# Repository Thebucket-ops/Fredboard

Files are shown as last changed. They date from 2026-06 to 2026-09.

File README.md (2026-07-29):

# ***THE FREDBOARD V1/V2***
fred is the seal

  The fredboard is a custom pi pico devboard:
  - the v2 has a MPU-6500 and has a reboot button with a led to indicate the restart;
  - the v1 (untested) allows to use all but one pins provided by the rp2040, and has a led to indicate when the devboard is powered

## **V2 (TO BE APPROVED)**

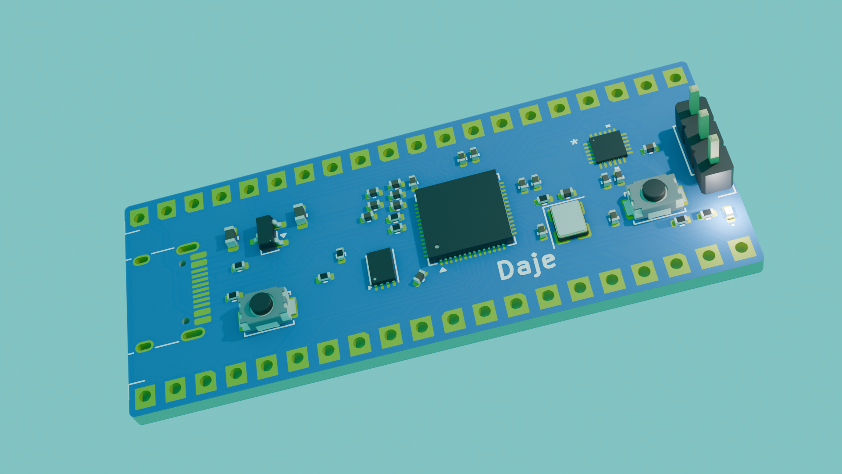
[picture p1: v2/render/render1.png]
front of the fredboard v2 boring side of the fredboard

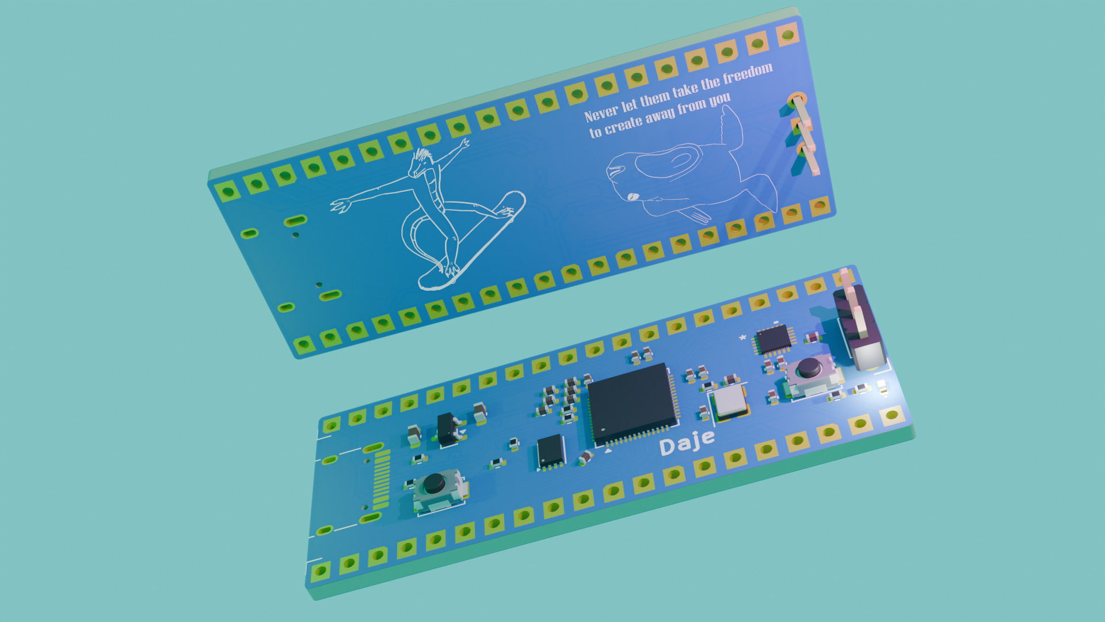
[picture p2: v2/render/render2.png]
back of the fredboard v2 look at that lizard smiling while riding his long skateboard

(Fred is the sea lion)

### **SCHEMATICS**
  Here's the schematic for the pcb, you can see the whole project from /v2/PCB

The Schematic for the v2 project schematic

### **THE PCB**
  This is the pcb, front and back (image art can be found on /img/devboard):

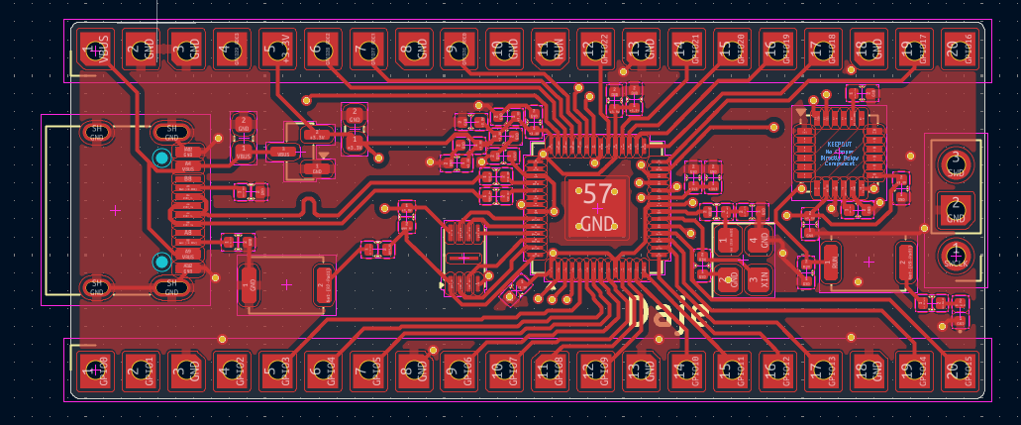
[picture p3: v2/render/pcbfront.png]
The pcb front v2 PCB front

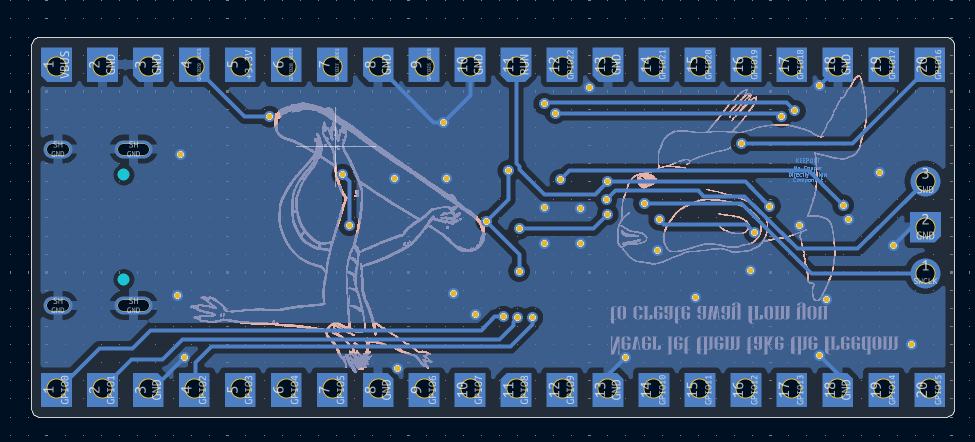
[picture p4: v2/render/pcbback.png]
The pcb back v2 PCB front


### **PINOUT**
  Here's a diagram for the pinout of the v2, for more information on each pins capabilities, look up the rp2040 datasheet

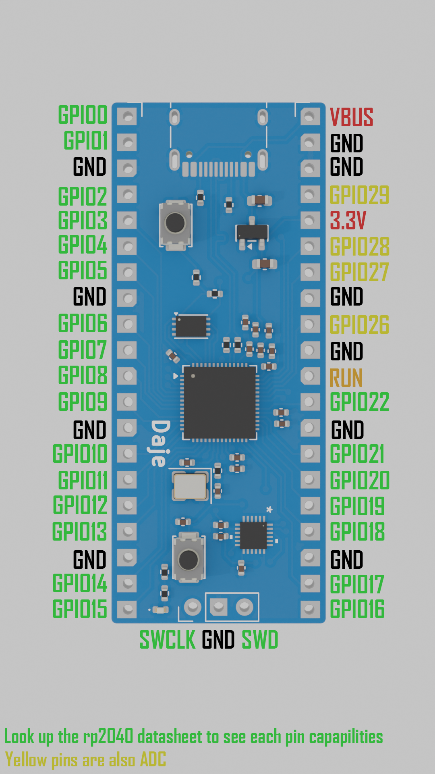
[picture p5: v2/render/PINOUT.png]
pinout


### **BOM and Gerber**
  The Bill Of Materials and the Gerber files can be found in the /v2/PCB/production folder, these are the required materials:

 - 2 33pF 0402 capacitors
 - 13 0.1uF 0402 capacitors
 - 2 1uF 0402 capacitors
 - 2 10uF 0603 capacitors
 - 1 10 nF 0402 capacitor
 - 1 0402 white led
 - 1 USB_C_Receptacle_USB2.0_14P
 - 2 pinheaders 1x20 (optional)
 - 1 pinheader 1x3 (optional)
 - 2 0402 27 ohm resistors
 - 1 0402 150 ohm resistor
 - 3 0402 1K resistors
 - 2 0402 5.1K resistors
 - 1 0402 10K resistor
 - 2 SW_Push_SPST_NO_Alps_SKRK button
 - 1 RP2040
 - 1 MCP1700x-330xxTT
 - 1 W25Q16JVUXIQ TR flash memory
 - 1 Crystal_SMD_3225-4Pin_3.2x2.5mm
 - 1 MPU-6500

## **V1 (UNTESTED)**
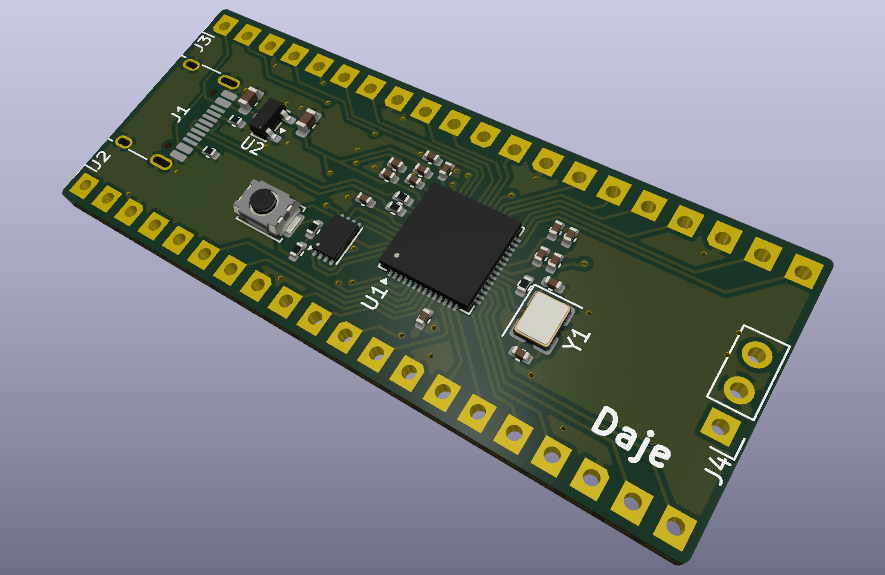
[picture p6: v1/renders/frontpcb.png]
front of the fredboard boring side of the fredboard

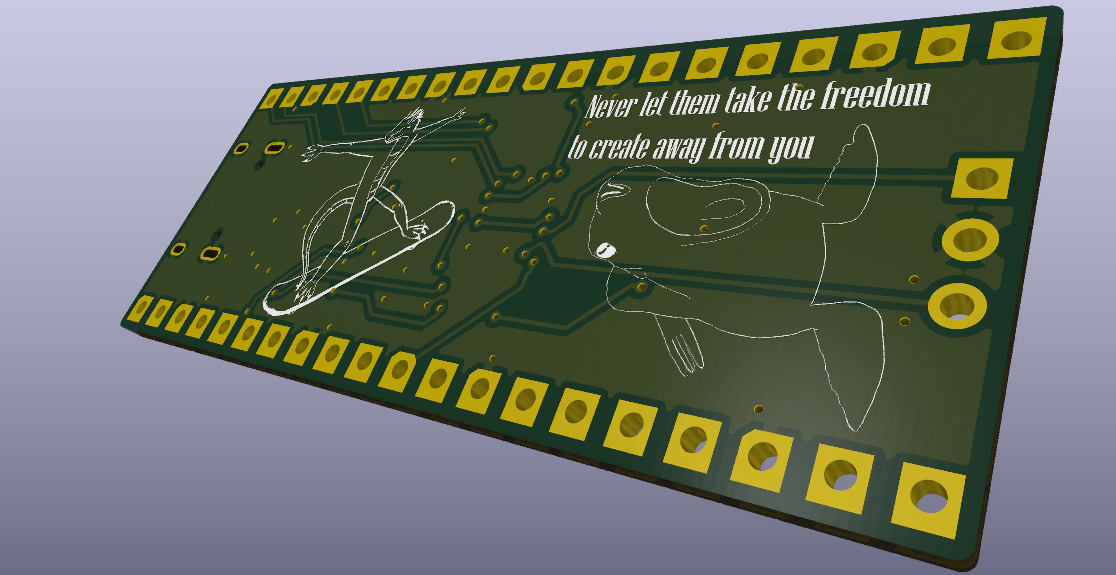
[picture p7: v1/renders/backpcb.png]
back of the fredboard look at that lizard smiling while riding his long skateboard


### **SCHEMATICS**
  Here's the schematic for the pcb, you can see the whole project from /PCB

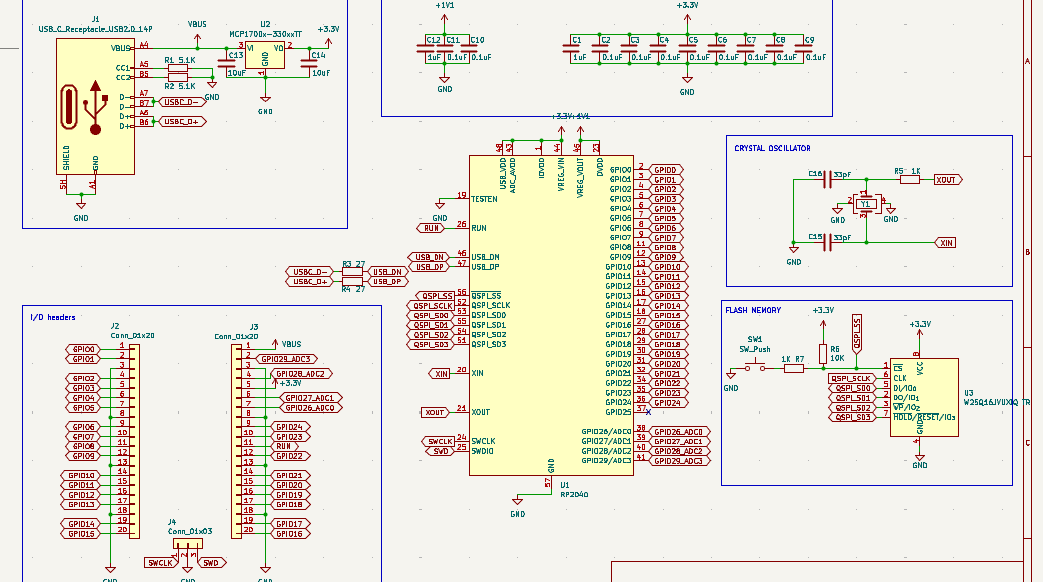
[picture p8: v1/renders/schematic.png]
The Schematic for the project schematic


### **THE PCB**
  This is the pcb, front and back (image art can be found on /img/devboard):

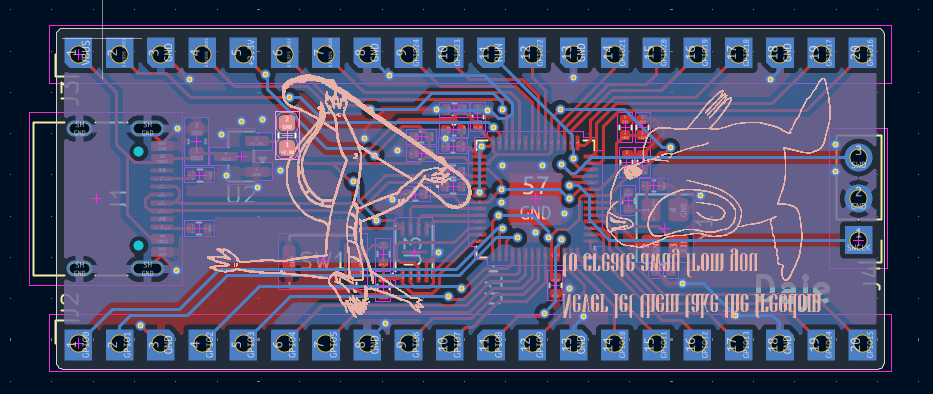
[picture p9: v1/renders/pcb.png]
The pcb PCB


### **BOM and Gerber**
  The Bill Of Materials and the Gerber files can be found in the /PCB/production folder, these are the required materials:

 - 10 0.1uF 0402 capacitors
 - 2 1uF 0402 capacitors
 - 2 10uF 0603 capacitors
 - 2 33pF 0402 capacitors
 - 1 0402 white led
 - 1 USB_C_Receptacle_USB2.0_14P
 - 2 pinheaders 1x20 (optional)
 - 1 pinheader 1x3 (optional)
 - 2 0402 5.1K resistors
 - 2 0402 27 ohm resistors
 - 2 0402 1K resistors
 - 1 0402 10K resistor
 - 1 SW_Push_SPST_NO_Alps_SKRK button
 - 1 RP2040
 - 1 MCP1700x-330xxTT
 - 1 W25Q16JVUXIQ TR flash memory
 - 1 Crystal_SMD_3225-4Pin_3.2x2.5mm

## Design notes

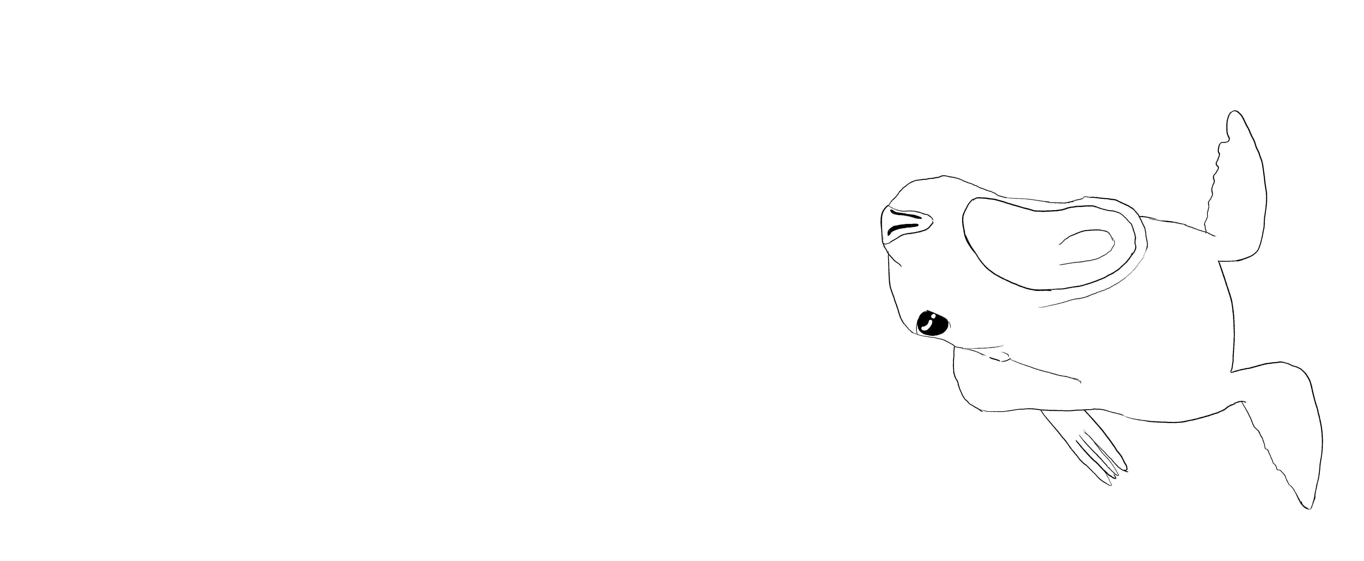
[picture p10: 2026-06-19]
img/devboard-art/seal.png

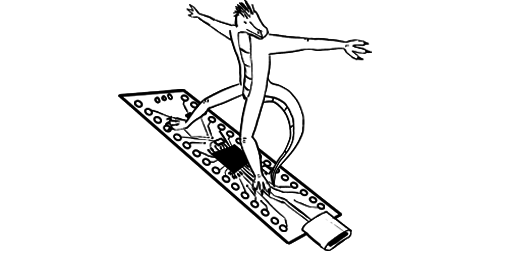
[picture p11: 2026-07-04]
siteimage.png

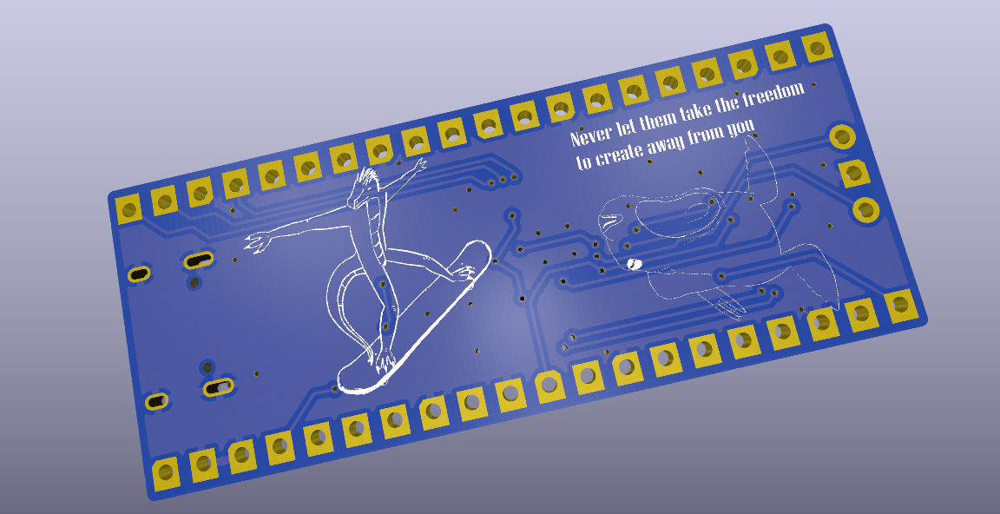
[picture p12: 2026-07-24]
v2/render/devboardback.png

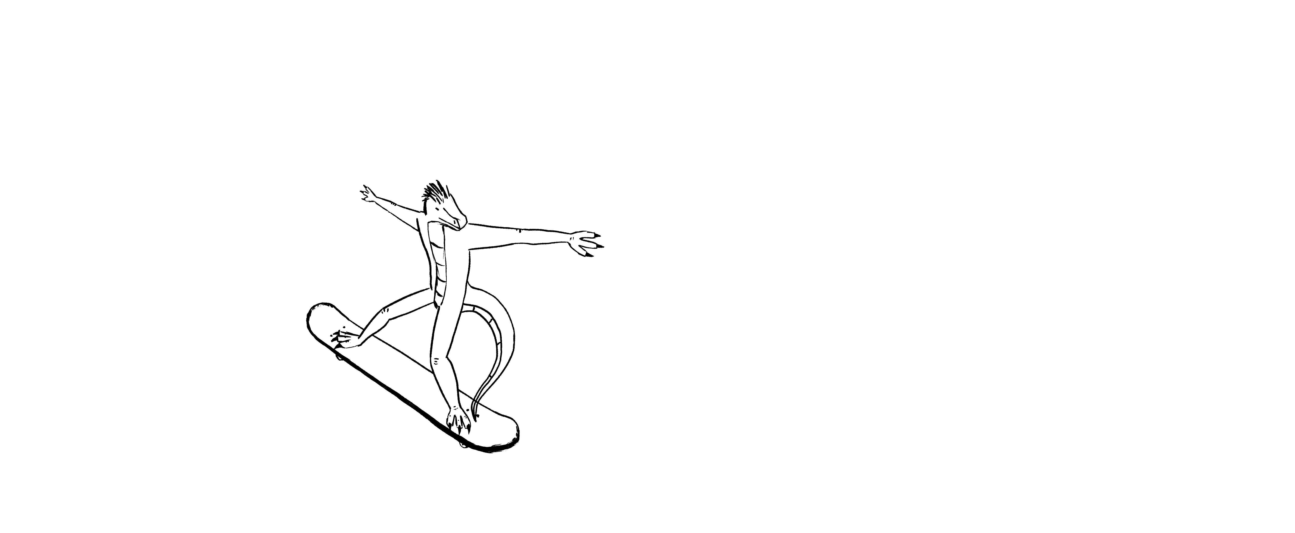
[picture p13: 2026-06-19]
img/devboard-art/fred.png

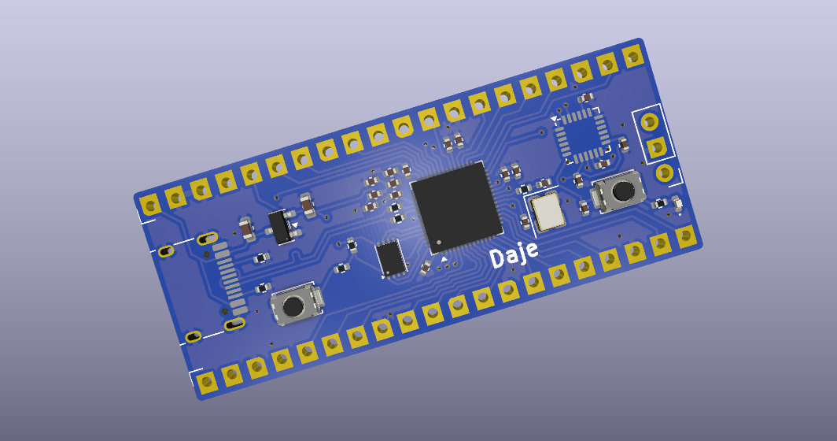
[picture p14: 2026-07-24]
v2/render/devboard.png

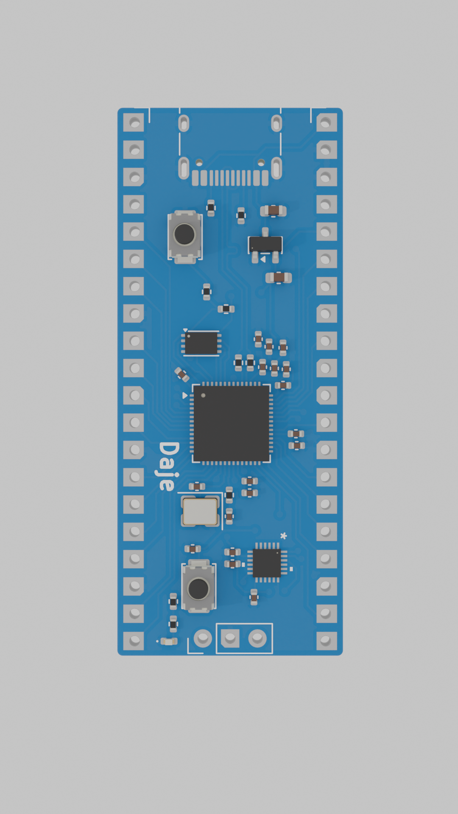
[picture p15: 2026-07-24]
v2/render/render3.png

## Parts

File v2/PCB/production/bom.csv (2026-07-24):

Designator | Footprint | Quantity | Value | LCSC Part #
C1, C12 | 0402 | 2 | 1uF
C10, C11, C18, C2, C20, C3, C4, C5, C6, C7, C8, C9 | 0402 | 12 | 0.1uF
C13, C14 | 0603 | 2 | 10uF
C15, C16 | 0402 | 2 | 33pF
C21 | 0402 | 1 | 100nF
C22 | 0402 | 1 | 10nF
D2 | 0402 | 1 | LED
J1 | USB_C_Receptacle_HRO_TYPE-C-31-M-12 | 1 | USB_C_Receptacle_USB2.0_14P
J2, J3 | PinHeader_1x20_P2.54mm_Vertical | 2 | Conn_01x20
J4 | PinHeader_1x03_P2.54mm_Vertical | 1 | Conn_01x03
R1, R2 | 0402 | 2 | 5.1K
R3, R4 | 0402 | 2 | 27
R5, R7, R8 | 0402 | 3 | 1K
R6 | 0402 | 1 | 10K
R9 | 0402 | 1 | 150
SW1, SW2 | SW_Push_SPST_NO_Alps_SKRK | 2 | SW_Push
U1 | QFN-56-1EP_7x7mm_P0.4mm_EP3.2x3.2mm | 1 | RP2040
U2 | SOT-23 | 1 | MCP1700x-330xxTT
U3 | Winbond_USON-8-1EP_3x2mm_P0.5mm_EP0.2x1.6mm | 1 | W25Q16JVUXIQ TR
U5 | QFN24_3X3X0P9_IVS | 1 | MPU-6500
Y1 | Crystal_SMD_3225-4Pin_3.2x2.5mm | 1 | Crystal_GND24

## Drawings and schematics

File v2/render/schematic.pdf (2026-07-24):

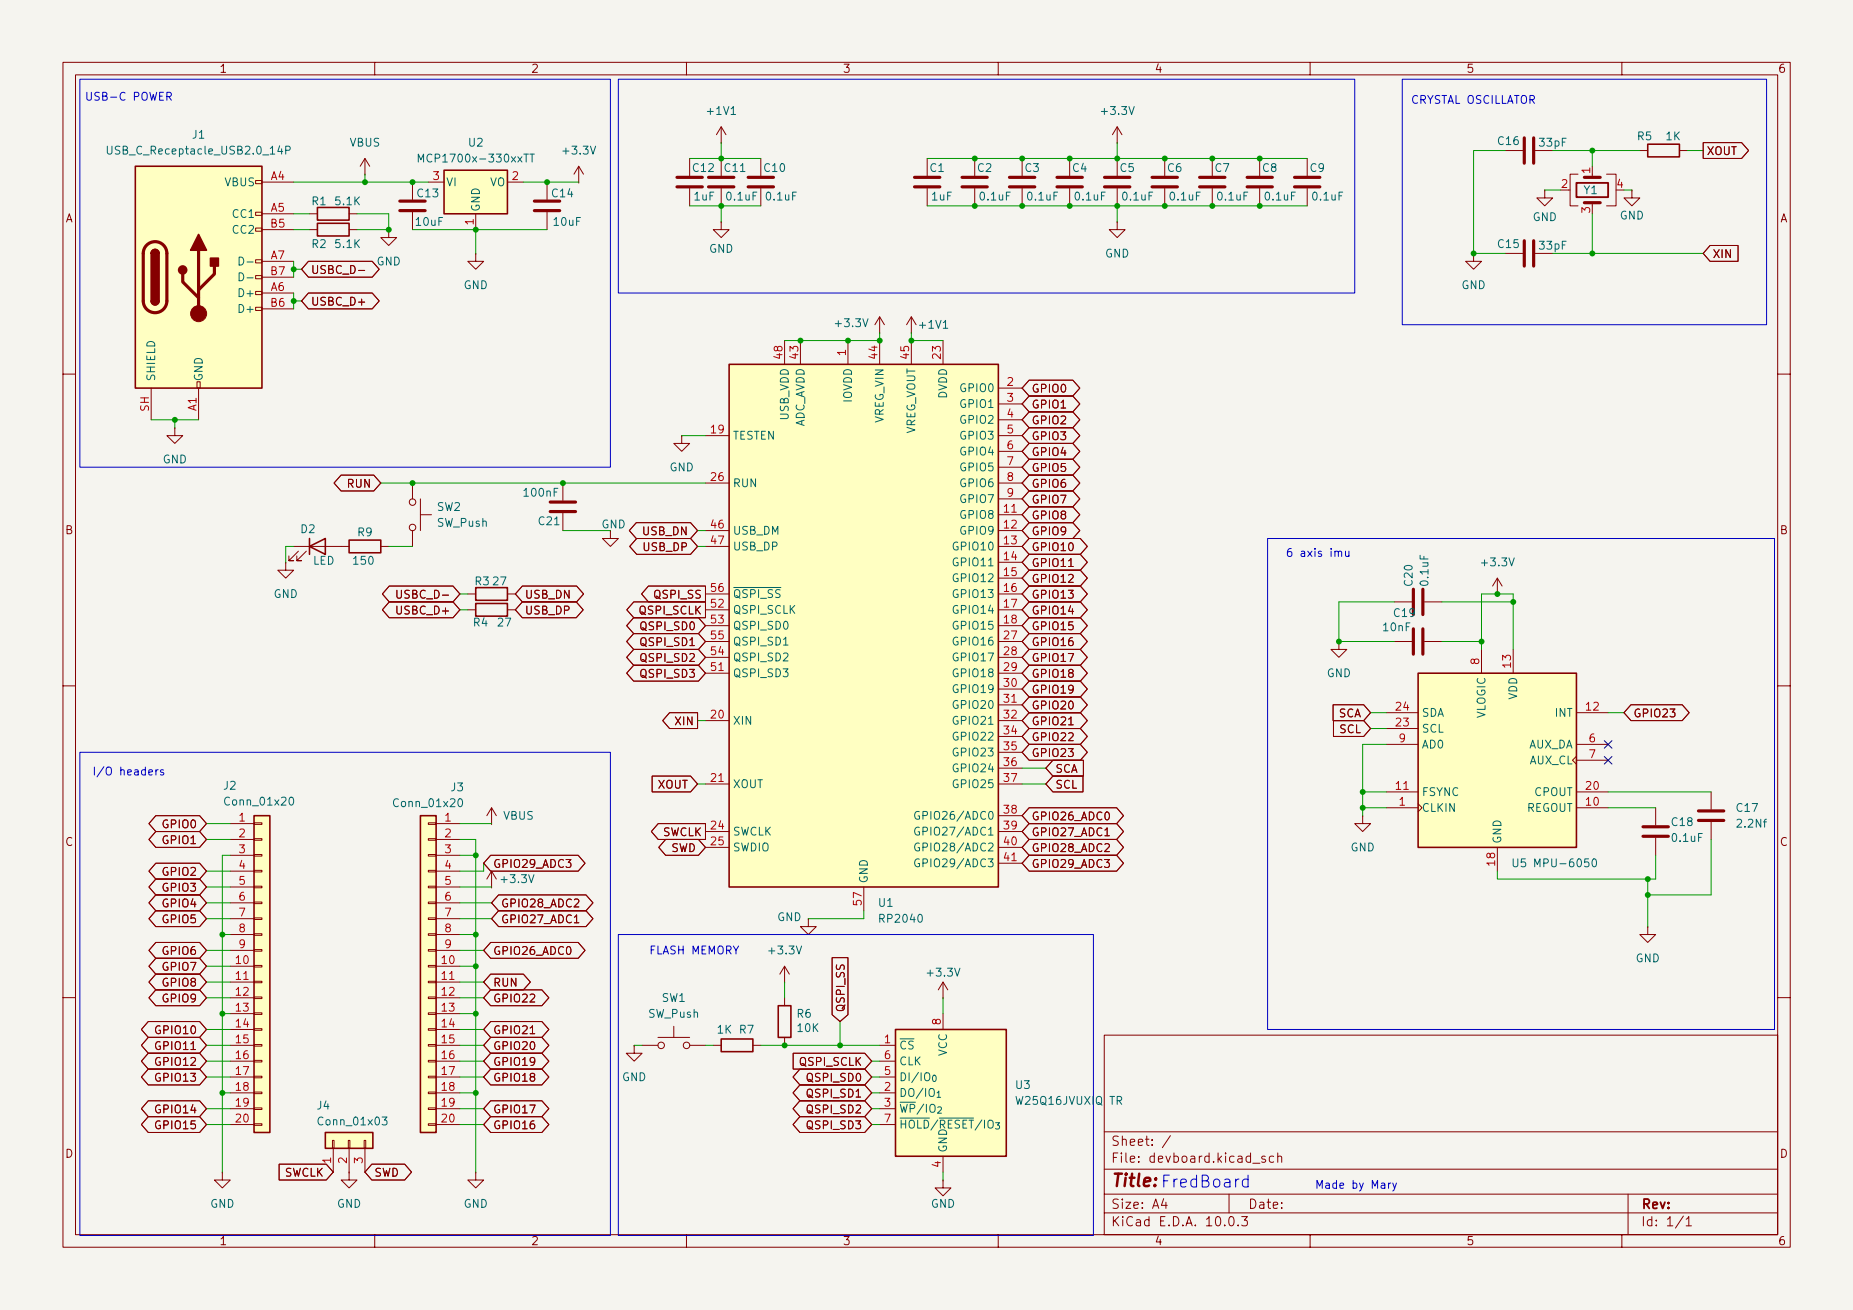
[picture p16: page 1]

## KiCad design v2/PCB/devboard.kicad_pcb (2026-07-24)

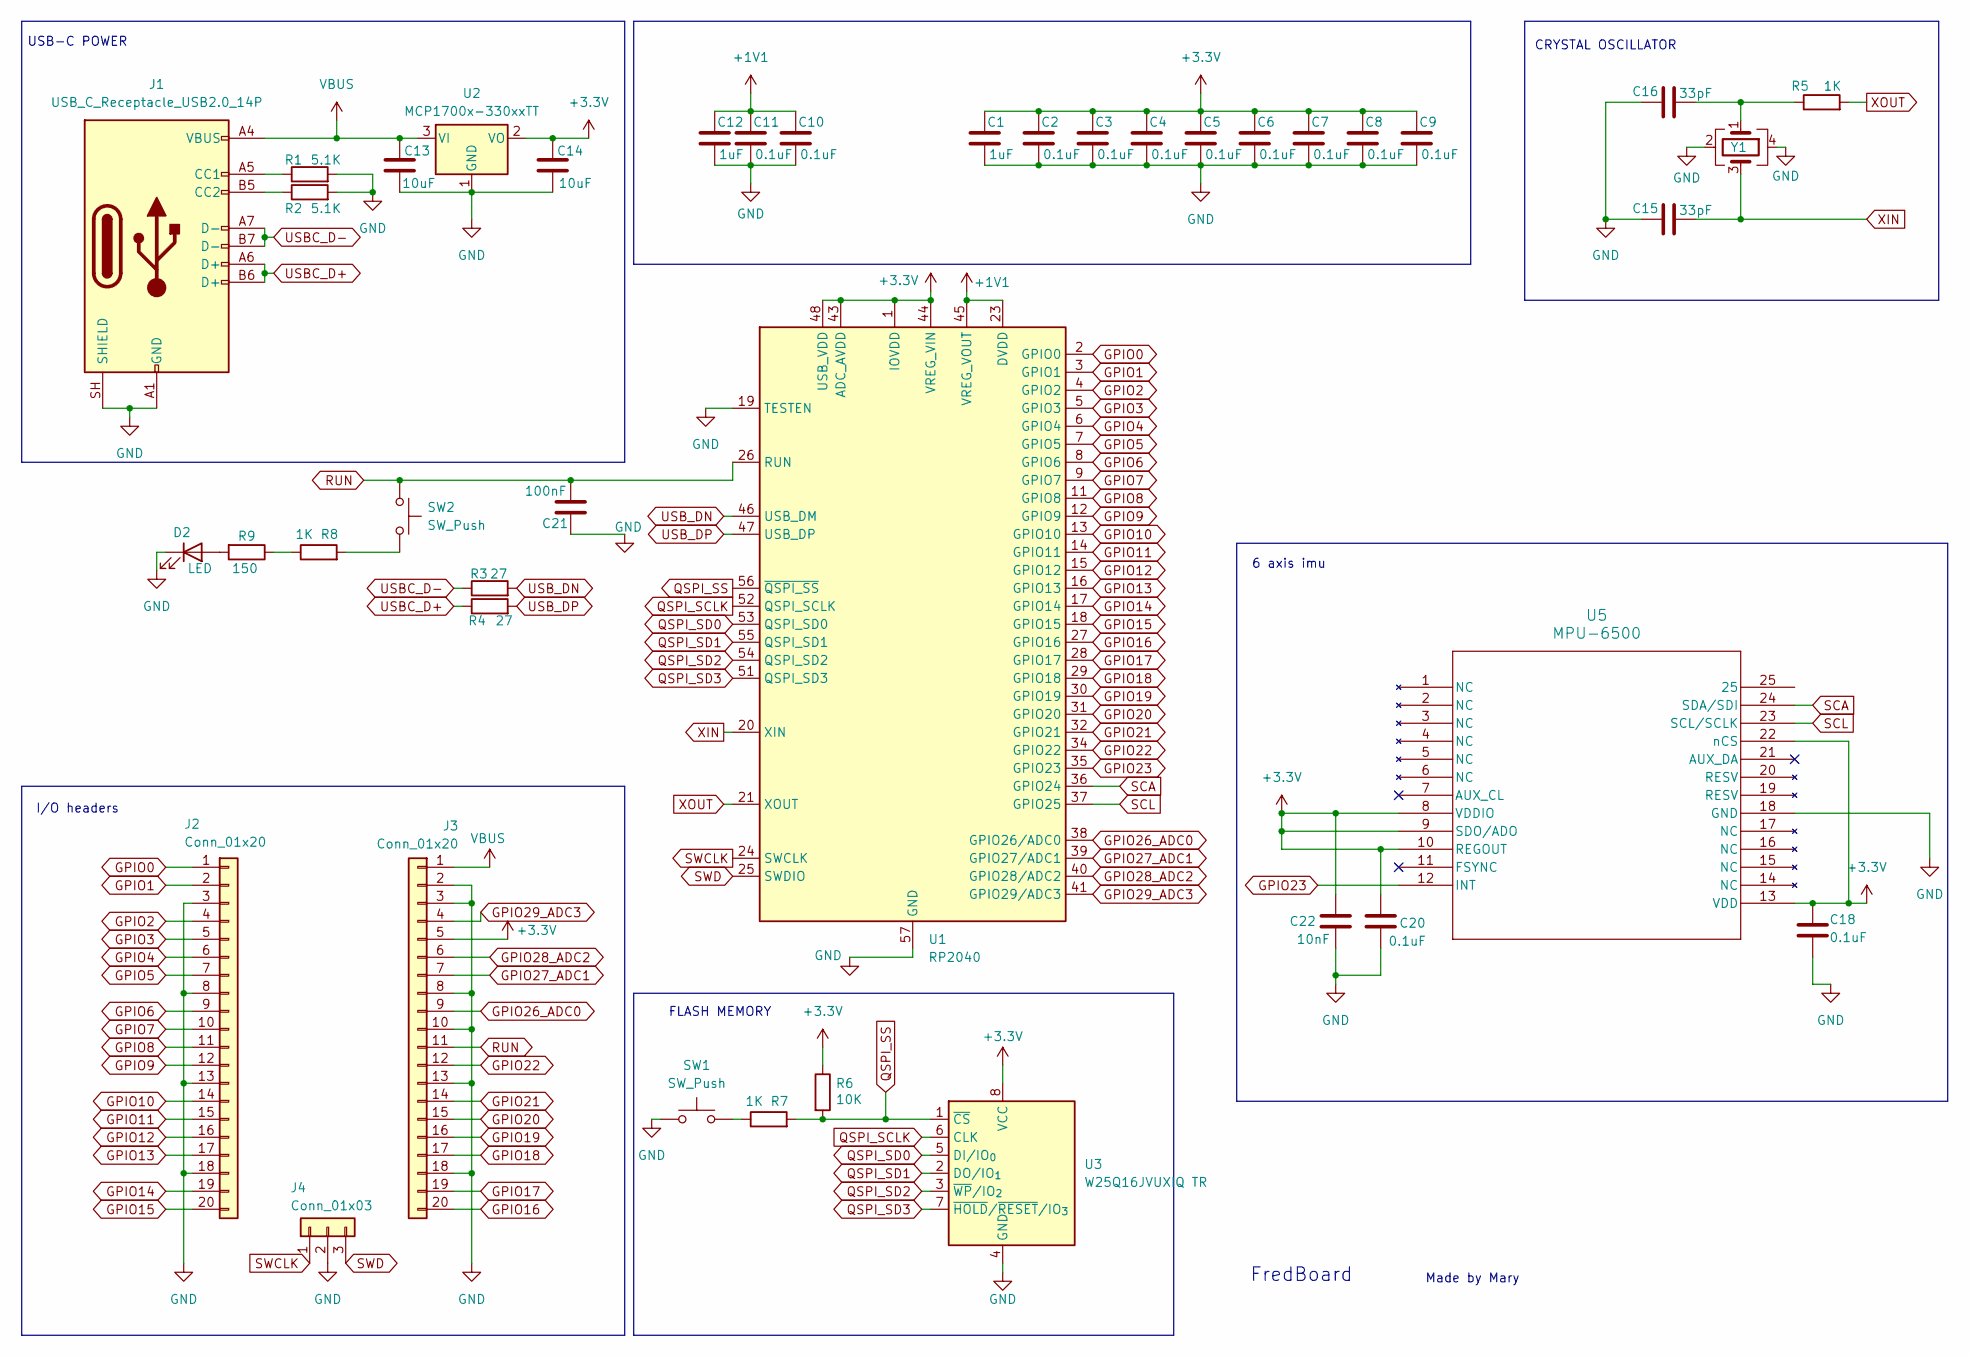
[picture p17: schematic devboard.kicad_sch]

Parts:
C1, C12: 1uF; C_0402_1005Metric
C2, C3, C4, C5, C6, C7, C8, C9, C10, C11, C18, C20: 0.1uF; C_0402_1005Metric
C13, C14: 10uF; C_0603_1608Metric
C15, C16: 33pF; C_0402_1005Metric
C21: 100nF; C_0402_1005Metric
C22: 10nF; C_0402_1005Metric
D2: LED; LED_0402_1005Metric
J1: USB_C_Receptacle_USB2.0_14P; USB_C_Receptacle_HRO_TYPE-C-31-M-12
J2, J3: Conn_01x20; PinHeader_1x20_P2.54mm_Vertical
J4: Conn_01x03; PinHeader_1x03_P2.54mm_Vertical
R1, R2: 5.1K; R_0402_1005Metric
R3, R4: 27; R_0402_1005Metric
R5, R7, R8: 1K; R_0402_1005Metric
R6: 10K; R_0402_1005Metric
R9: 150; R_0402_1005Metric
SW1, SW2: SW_Push; SW_Push_SPST_NO_Alps_SKRK
U1: RP2040; QFN-56-1EP_7x7mm_P0.4mm_EP3.2x3.2mm
U2: MCP1700x-330xxTT; SOT-23
U3: W25Q16JVUXIQ TR; Winbond_USON-8-1EP_3x2mm_P0.5mm_EP0.2x1.6mm
U5: MPU-6500; QFN24_3X3X0P9_IVS
Y1: Crystal_GND24; Crystal_SMD_3225-4Pin_3.2x2.5mm

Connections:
+1V1: C10.1, C11.1, C12.1, U1.23 (DVDD), U1.45 (VREG_VOUT), U1.50 (DVDD)
+3.3V: C1.1, C2.1, C3.1, C4.1, C5.1, C6.1, C7.1, C8.1, C9.1, C14.1, C18.1, C20.1, C22.1, J3.5, R6.1, U1.1 (IOVDD), U1.10 (IOVDD), U1.22 (IOVDD), U1.33 (IOVDD), U1.42 (IOVDD), U1.43 (ADC_AVDD), U1.44 (VREG_VIN), U1.48 (USB_VDD), U1.49 (IOVDD), U2.2 (VO), U3.8 (VCC), U5.8 (VDDIO), U5.9 (SDO/ADO), U5.10 (REGOUT), U5.13 (VDD), U5.22 (nCS)
GND: C1.2, C2.2, C3.2, C4.2, C5.2, C6.2, C7.2, C8.2, C9.2, C10.2, C11.2, C12.2, C13.2, C14.2, C15.1, C16.1, C18.2, C20.2, C21.1, C22.2, D2.1 (K), J1.A1 (GND), J1.A12 (GND), J1.B1 (GND), J1.B12 (GND), J1.SH (SHIELD), J2.3, J2.8, J2.13, J2.18, J3.2, J3.3, J3.8, J3.10, J3.13, J3.18, J4.2, R1.2, R2.2, SW1.1, U1.19 (TESTEN), U1.57 (GND), U2.1 (GND), U3.4 (GND), U5.18 (GND), Y1.2 (G), Y1.4 (G)
GPIO0: J2.1, U1.2 (GPIO0)
GPIO1: J2.2, U1.3 (GPIO1)
GPIO2: J2.4, U1.4 (GPIO2)
GPIO3: J2.5, U1.5 (GPIO3)
GPIO4: J2.6, U1.6 (GPIO4)
GPIO5: J2.7, U1.7 (GPIO5)
GPIO6: J2.9, U1.8 (GPIO6)
GPIO7: J2.10, U1.9 (GPIO7)
GPIO8: J2.11, U1.11 (GPIO8)
GPIO9: J2.12, U1.12 (GPIO9)
GPIO10: J2.14, U1.13 (GPIO10)
GPIO11: J2.15, U1.14 (GPIO11)
GPIO12: J2.16, U1.15 (GPIO12)
GPIO13: J2.17, U1.16 (GPIO13)
GPIO14: J2.19, U1.17 (GPIO14)
GPIO15: J2.20, U1.18 (GPIO15)
GPIO16: J3.20, U1.27 (GPIO16)
GPIO17: J3.19, U1.28 (GPIO17)
GPIO18: J3.17, U1.29 (GPIO18)
GPIO19: J3.16, U1.30 (GPIO19)
GPIO20: J3.15, U1.31 (GPIO20)
GPIO21: J3.14, U1.32 (GPIO21)
GPIO22: J3.12, U1.34 (GPIO22)
GPIO23: U1.35 (GPIO23), U5.12 (INT)
GPIO26_ADC0: J3.9, U1.38 (GPIO26/ADC0)
GPIO27_ADC1: J3.7, U1.39 (GPIO27/ADC1)
GPIO28_ADC2: J3.6, U1.40 (GPIO28/ADC2)
GPIO29_ADC3: J3.4, U1.41 (GPIO29/ADC3)
unnamed: C16.2, R5.1, Y1.1
unnamed: D2.2 (A), R9.2
unnamed: J1.A5 (CC1), R1.1
unnamed: J1.B5 (CC2), R2.1
unnamed: R7.1, SW1.2
unnamed: R8.1, R9.1
unnamed: R8.2, SW2.2
QSPI_SCLK: U1.52 (QSPI_SCLK), U3.6 (CLK)
QSPI_SD0: U1.53 (QSPI_SD0), U3.5 (DI/IO_{0})
QSPI_SD1: U1.55 (QSPI_SD1), U3.2 (DO/IO_{1})
QSPI_SD2: U1.54 (QSPI_SD2), U3.3 (~WP/IO_{2})
QSPI_SD3: U1.51 (QSPI_SD3), U3.7 (~HOLD/~RESET/IO_{3})
QSPI_SS: R6.2, R7.2, U1.56 (~QSPI_SS), U3.1 (~CS)
RUN: C21.2, J3.11, SW2.1, U1.26 (RUN)
SCA: U1.36 (GPIO24), U5.24 (SDA/SDI)
SCL: U1.37 (GPIO25), U5.23 (SCL/SCLK)
SWCLK: J4.1, U1.24 (SWCLK)
SWD: J4.3, U1.25 (SWDIO)
USBC_D+: J1.A6 (D+), J1.B6 (D+), R4.1
USBC_D-: J1.A7 (D-), J1.B7 (D-), R3.1
USB_DN: R3.2, U1.46 (USB_DM)
USB_DP: R4.2, U1.47 (USB_DP)
VBUS: C13.1, J1.A4 (VBUS), J1.A9 (VBUS), J1.B4 (VBUS), J1.B9 (VBUS), J3.1, U2.3 (VI)
XIN: C15.2, U1.20 (XIN), Y1.3
XOUT: R5.2, U1.21 (XOUT)

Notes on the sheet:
FLASH MEMORY
CRYSTAL OSCILLATOR
USB-C POWER
Made by Mary
FredBoard
6 axis imu
I/O headers

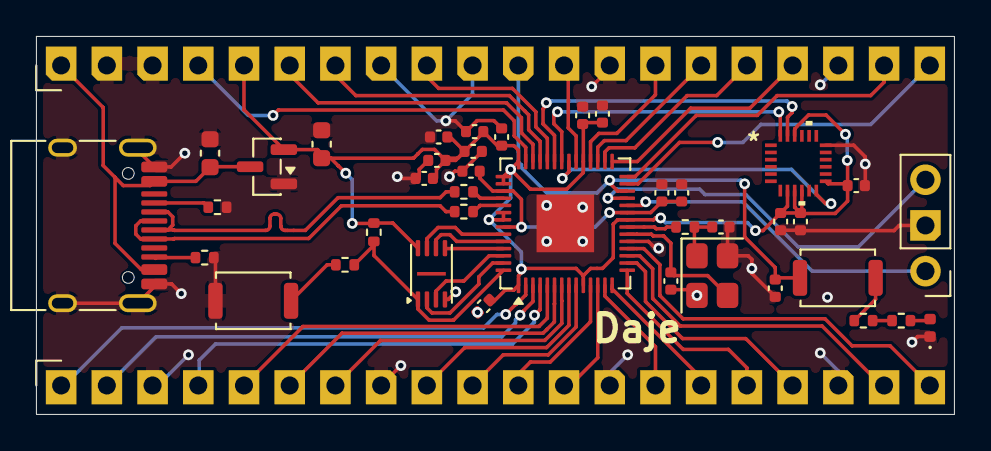
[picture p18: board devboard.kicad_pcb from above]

Board: 2 copper layers, 51.0 x 21.0 mm, 41 parts (0 on the bottom side), 56 nets.

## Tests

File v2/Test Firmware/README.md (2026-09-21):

# ** DISCLAIMER **

### this test firmware uses the mp92plus library from Optimunn in order to work, all credits go to him, check him out here, will make a better version of the firmware once i get my hands on it, thank you for your patience :]

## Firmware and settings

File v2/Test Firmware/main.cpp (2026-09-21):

/*
 * Example for the mp92plus library (MPU6500)
 *
 * This example shows how to get acceleration,
 * gyroscope, and temperature data from the MPU6050 using interrupts.
 *
 * The sensor uses the i2c interface in this example.
 *
 * Don't forget to set
 * #define MP92_USE_COMPASS false
 * #define MP92_USE_SPI false
 * in file mp92plus.h
 */

#include <stdio.h>
#include "pico/stdlib.h"
#include "mp92plus.h"

#define SDA_PIN 24
#define SCL_PIN 25
#define INTERRUPT_PIN 23
#define DEVICE_ADDRESS 0x68

mpu9250_t mpu92;

float accel[3], gyro[3], temp;

void IRQ_callback(void)
{
    // system: get irq mask
    uint32_t events = gpio_get_irq_event_mask(INTERRUPT_PIN);
    // system: irq on rise front
    if (events & GPIO_IRQ_EDGE_RISE)
    {
        mpu9250_read_motion(&mpu92, accel, gyro);
        mpu9250_read_temperature(&mpu92, &temp);
        printf("Acceleration in G     X = %10.4f,  Y = %10.4f,  Z = %10.4f\n", accel[0], accel[1], accel[2]);
        printf("Gyroscope in Deg/s    X = %10.4f,  Y = %10.4f,  Z = %10.4f\n", gyro[0], gyro[1], gyro[2]);
        printf("Temperature in C      %10.4f\n\n", temp);
        mpu9250_continue_interrupt(&mpu92);
    }
    // system: clear interrupt mask
    gpio_acknowledge_irq(INTERRUPT_PIN, events);
}

int main()
{
    stdio_init_all();
    sleep_ms(2000);

    uint8_t activate = mpu9250_reset(&mpu92, SDA_PIN, SCL_PIN, DEVICE_ADDRESS, i2c0, 100 * 1000);
    if (activate)
        printf("Failed to initialize MPU9250!\n");

    mpu_settings_t set = {
        .accel_range = ACCEL_RANGE_16G,
        .gyro_range = GYRO_RANGE_2000DPS,
        .dlpf_filter = DLPF_41HZ,
        .sample_rate_divider = 249};
    int16_t correct_gyro[] = {0, 0, 0};
    uint8_t settings = mpu9250_setup(&mpu92, &set, correct_gyro);
    if (settings)
        printf("Failed to setup MPU9250!\n");

    mpu9250_attach_interrupt(&mpu92, INTERRUPT_PIN, gpio_callback);

    while (1)
    {
        /* Other code */
        sleep_ms(1000);
    }
}

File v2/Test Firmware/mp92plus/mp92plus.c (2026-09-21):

#include "mp92plus.h"
#include "regmap.h"

#if MP92_USE_SPI
static inline void cs_select(uint pin_cs)
{
    gpio_put(pin_cs, 0);
    asm volatile("nop \n nop");
}

static inline void cs_deselect(uint pin_cs)
{
    gpio_put(pin_cs, 1);
    asm volatile("nop \n nop");
}

static inline void __attribute__((always_inline)) this_interface_init(spi_pin_t *spi_pins, spi_inst_t *inst, uint32_t frequency)
{
    spi_init(inst, frequency);
    gpio_set_function(spi_pins->miso, GPIO_FUNC_SPI);
    gpio_set_function(spi_pins->sck, GPIO_FUNC_SPI);
    gpio_set_function(spi_pins->mosi, GPIO_FUNC_SPI);

    gpio_init(spi_pins->cs);
    gpio_set_dir(spi_pins->cs, GPIO_OUT);
    gpio_put(spi_pins->cs, 1);
}
#else
static inline void __attribute__((always_inline)) this_interface_init(uint sda, uint scl, uint8_t addr, i2c_inst_t *inst, uint32_t frequency)
{
    i2c_init(inst, frequency);
    gpio_set_function(sda, GPIO_FUNC_I2C);
    gpio_set_function(scl, GPIO_FUNC_I2C);

    gpio_pull_up(sda);
    gpio_pull_up(scl);
}
#endif

static void mpu_write_reg(mpu9250_t *config, uint8_t addr, uint8_t reg)
{
    uint8_t buf[] = {addr, reg};
#if MP92_USE_SPI
    cs_select(config->cs);
    spi_write_blocking(config->inst, buf, 2);
    cs_deselect(config->cs);
#else
    i2c_write_blocking(config->inst, config->addr, buf, 2, false);
#endif
    busy_wait_us(550);
}

static void mpu_read_reg(mpu9250_t *config, uint8_t addr, uint8_t *buf, uint8_t len)
{
#if MP92_USE_SPI
    addr |= READ_CONST;
    cs_select(config->cs);
    spi_write_blocking(config->inst, &addr, 1);
    spi_read_blocking(config->inst, 0, buf, len);
    cs_deselect(config->cs);
#else
    i2c_write_blocking(config->inst, config->addr, &addr, 1, true);
    i2c_read_blocking(config->inst, config->addr, buf, len, false);
#endif
}

#if MP92_USE_COMPASS
static void mag_write_reg(mpu9250_t *config, uint8_t addr, uint8_t reg)
{
    mpu_write_reg(config, I2C_SLV0_ADDR, AK8963_I2C_ADDR);
    mpu_write_reg(config, I2C_SLV0_REG, addr);
    mpu_write_reg(config, I2C_SLV0_DO, reg);
    mpu_write_reg(config, I2C_SLV0_CTRL, I2C_SLV0_EN | (uint8_t)1);
}

static void mag_enable_reg(mpu9250_t *config, uint8_t addr, uint8_t len)
{
    mpu_write_reg(config, I2C_SLV0_ADDR, AK8963_I2C_ADDR | I2C_READ_FLAG);
    mpu_write_reg(config, I2C_SLV0_REG, addr);
    mpu_write_reg(config, I2C_SLV0_CTRL, I2C_SLV0_EN | len);
    busy_wait_ms(1);
}

static void mag_read_reg(mpu9250_t *config, uint8_t addr, uint8_t *buf, uint8_t len)
{
    mag_enable_reg(config, addr, len);
    mpu_read_reg(config, EXT_SENS_DATA_00, buf, len);
}

static inline __attribute__((always_inline)) void mag_get_asa_values(mpu9250_t *config)
{
    uint8_t buf[3];
    mag_read_reg(config, AK8963_ASAX, buf, sizeof(buf));
    for (uint8_t item = 0; item < 3; item++)
        config->asa_values[item] = (0.5 * (buf[item] - 128) / 128.0) + 1.0;
}
#endif

static uint8_t mpu6500_status(mpu9250_t *config)
{
    uint8_t buf;
    mpu_read_reg(config, WHO_AM_I, &buf, 1);
    return (buf == 0x71 || buf == 0x73) ? 0 : 1;
}

#if MP92_USE_COMPASS
static uint8_t ak8963_status(mpu9250_t *config)
{
    uint8_t buf;
    mag_read_reg(config, AK8963_WHO_AM_I, &buf, 1);
    return (buf == 0x48) ? 0 : 1;
}
#endif

#if MP92_USE_SPI
error_t mpu9250_reset(mpu9250_t *config, spi_pin_t *spi_pins, spi_inst_t *inst, uint32_t frequency)
{
    config->cs = spi_pins->cs;
    config->inst = inst;

    this_interface_init(spi_pins, inst, frequency);

    config->interrupt = 0x80;

    return mpu_init_default(config);
}
#else
error_t mpu9250_reset(mpu9250_t *config, uint sda, uint scl, uint8_t addr, i2c_inst_t *inst, uint32_t frequency)
{
    config->addr = addr;
    config->inst = inst;

    this_interface_init(sda, scl, addr, inst, frequency);

    config->interrupt = 0x80;

    return mpu_init_default(config);
}
#endif

static inline __attribute__((always_inline)) error_t mpu_init_default(mpu9250_t *config)
{
    mpu_write_reg(config, PWR_MGMNT_1, CLOCK_SEL_PLL);

    mpu_write_reg(config, PWR_MGMNT_1, PWR_RESET);
    busy_wait_ms(1);

    mpu_write_reg(config, PWR_MGMNT_1, CLOCK_SEL_PLL);

    if (mpu6500_status(config))
        return 1;

    mpu_write_reg(config, PWR_MGMNT_2, SEN_ENABLE);
    mpu_write_reg(config, INT_PIN_CFG, BYPASS_EN);

    // setting accel range to 16G as default
    mpu_write_reg(config, ACCEL_CONFIG, ACCEL_FS_SEL_16G);
    config->factors[0] = 16.0f / 32767.5f;

    // setting the gyro range to 2000DPS as default
    mpu_write_reg(config, GYRO_CONFIG, GYRO_FS_SEL_2000DPS & ~0x03);
    config->factors[1] = 2000.0f / 32767.5f;

    // setting bandwidth to 184Hz as default
    mpu_write_reg(config, CONFIG, DLPF_184);
    mpu_write_reg(config, ACCEL_CONFIG2, DLPF_184 & ~0x08);

#if MP92_USE_COMPASS
    mpu_write_reg(config, SMPDIV, 0x00);

    mpu_write_reg(config, USER_CTRL, I2C_MST_EN);
    mpu_write_reg(config, I2C_MST_CTRL, I2C_MST_CLK);

    mag_write_reg(config, AK8963_CNTL1, AK8963_PWR_DOWN);

    mag_write_reg(config, AK8963_CNTL2, AK8963_RESET);
    busy_wait_ms(1);

    if (ak8963_status(config))
        return 2;

    mag_write_reg(config, AK8963_CNTL1, AK8963_PWR_DOWN);

    mag_write_reg(config, AK8963_CNTL1, AK8963_FUSE_ROM);

    mag_get_asa_values(config);

    mag_write_reg(config, AK8963_CNTL1, AK8963_PWR_DOWN);

    mag_write_reg(config, AK8963_CNTL1, AK8963_CNT_MEAS2);
#endif

    mpu_write_reg(config, PWR_MGMNT_1, CLOCK_SEL_PLL);

    mpu_write_reg(config, SMPDIV, 0x09);

#if MP92_USE_COMPASS
    mag_enable_reg(config, AK8963_HXL, 7);
#endif

    return 0;
}

error_t mpu9250_setup(mpu9250_t *config, mpu_settings_t *settings, int16_t gyro_zero[3])
{
    uint8_t gyro_bytes[6];

    for (int item = 0; item < 3; item++)
    {
        gyro_bytes[2 * item] = (0 - gyro_zero[item] >> 8) & 0xFF;
        gyro_bytes[2 * item + 1] = 0 - gyro_zero[item] & 0xFF;
    }

    for (uint8_t item = 0; item < 6; item++)
        mpu_write_reg(config, XG_OFFSET_H + item, gyro_bytes[item]);

    switch (settings->accel_range)
    {
    case ACCEL_RANGE_2G:
        config->factors[0] = 2.0f / 32767.5f;
        break;
    case ACCEL_RANGE_4G:
    case ACCEL_RANGE_8G:
        config->factors[0] = settings->accel_range / 2.0f / 32767.5f;
        break;
    case ACCEL_RANGE_16G:
        config->factors[0] = 16.0f / 32767.5f;
        break;
    }
    mpu_write_reg(config, ACCEL_CONFIG, settings->accel_range);

    switch (settings->gyro_range)
    {
    case GYRO_RANGE_250DPS:
        config->factors[1] = 250.0f / 32767.5f;
        break;
    case GYRO_RANGE_500DPS:
    case GYRO_RANGE_1000DPS:
        config->factors[1] = settings->gyro_range * 62.5f / 32767.5f;
        break;
    case GYRO_RANGE_2000DPS:
        config->factors[1] = 2000.0f / 32767.5f;
        break;
    }
    mpu_write_reg(config, GYRO_CONFIG, settings->gyro_range & ~0x03);

    mpu_write_reg(config, CONFIG, settings->dlpf_filter);
    mpu_write_reg(config, ACCEL_CONFIG2, settings->dlpf_filter & ~0x08);
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

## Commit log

2026-06-19 reordering repo
    [bom.csv, designators.csv, devboard.kicad_pcb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]
2026-06-19 updating readme and pcb
    [devboard.kicad_pcb, devboard.kicad_sch]
2026-06-27 added v1 folder
    added leds to the v1 board and created a v2 folder
    [bom.csv, designators.csv, devboard.kicad_pcb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]
2026-07-19 added imu to the v2 and created/wired pcb
    [devboard.kicad_pcb, devboard.kicad_sch]
2026-07-24 updated pcb and made renders
    -Changed imu to a MPU-6500
    -moved some traces and changed some pads in the devboard
    -remade gerber and BOM
    -created renders of the v2
    -made pinout image of the v2
    [bom.csv, designators.csv, devboard v2.blend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]
2026-07-24 moved/updated files in the repo and updated readme
    [bom.csv, designators.csv, devboard.kicad_pcb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]
2026-07-24 moved away render files
    [devboard v2.blend]
2026-07-29 specified that fred is the seal in the back of the devboard
    just in case you would confuse
